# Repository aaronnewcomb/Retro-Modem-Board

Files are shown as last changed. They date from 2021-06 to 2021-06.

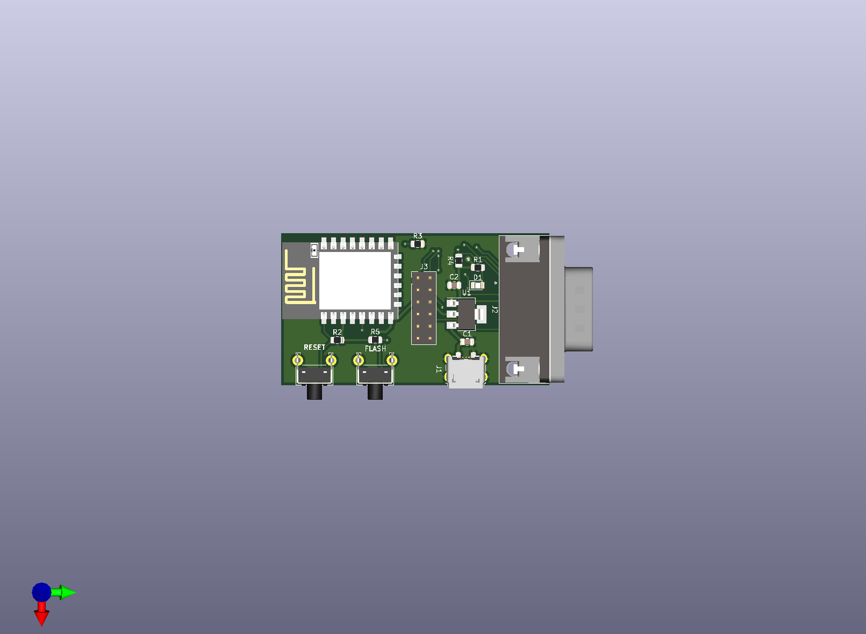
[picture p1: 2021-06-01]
KiCAD/RetroWIFI.png

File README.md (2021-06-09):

# Retro-Modem-Board
This is the PCB I built to be used with the Zmodem project

RetroWIFI

This boards uses an ESP8266 in the form of an ESP-12E/F module along with some simple parts to act as a modem/wifi bridge. It was initially built to be used with this Zmodem project. https://github.com/bozimmerman/Zimodem

3D printable case available here https://www.thingiverse.com/thing:4876405
## Video
thumbnail030 (https://youtu.be/1vX6TcwniQ4)

## BOM

\*All caps and resistors are 0805/2012
Label | Part
------------ | -------------
C1, C2 | 10uF Capacitor
C3 - C7 | .1uF Capacitor
D1 | 0805 LED
J1 | USB Micro-B socket
J2 | 9 Pin Female DSUB 4.94mm Edge Pin Offset
J3 | 02x06 Pin Header
R1 | 470 Ohm Resistor
R2 - R5 | 1K Ohm Resistor
SW1, SW2 | Push Button Right Angle
U1 | NCP1117ST33T3G
U2 | MAX3232
U3 | ESP-12E/F Module

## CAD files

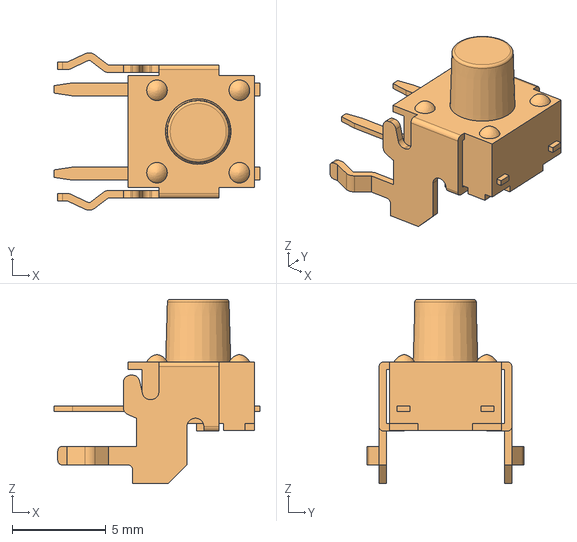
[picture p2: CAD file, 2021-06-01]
KiCAD/TL1105XFxxxx.stp
11.0 x 8.40 x 9.85 mm

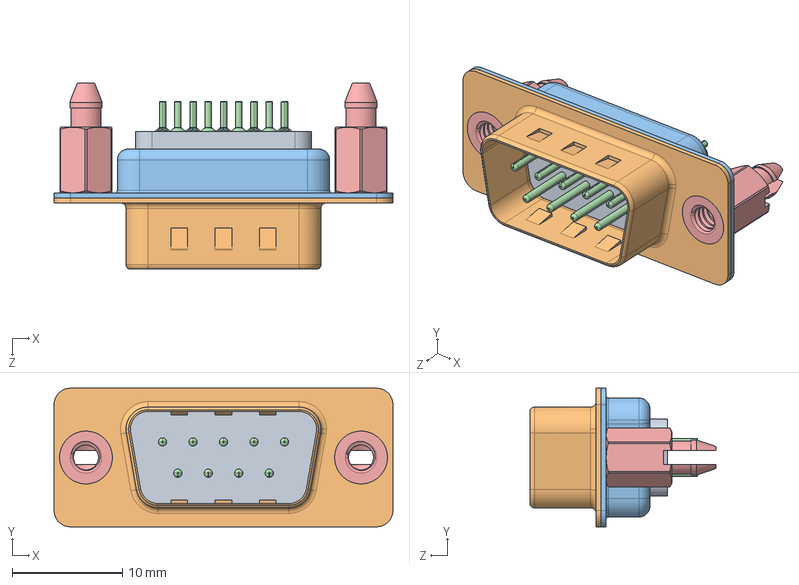
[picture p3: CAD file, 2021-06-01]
KiCAD/627-009-220-046 - EDAC D-Sub Connector.STEP
30.8 x 12.6 x 16.9 mm
627 Housing_09 LP
627 Shell Front_09 Contacts
627 Shell Rear_09 Contacts
627 Contact Row 1_20L x 5
627 Contact Row 2_20L x 4
627 4-40 Threaded Boardlock_LP x 2

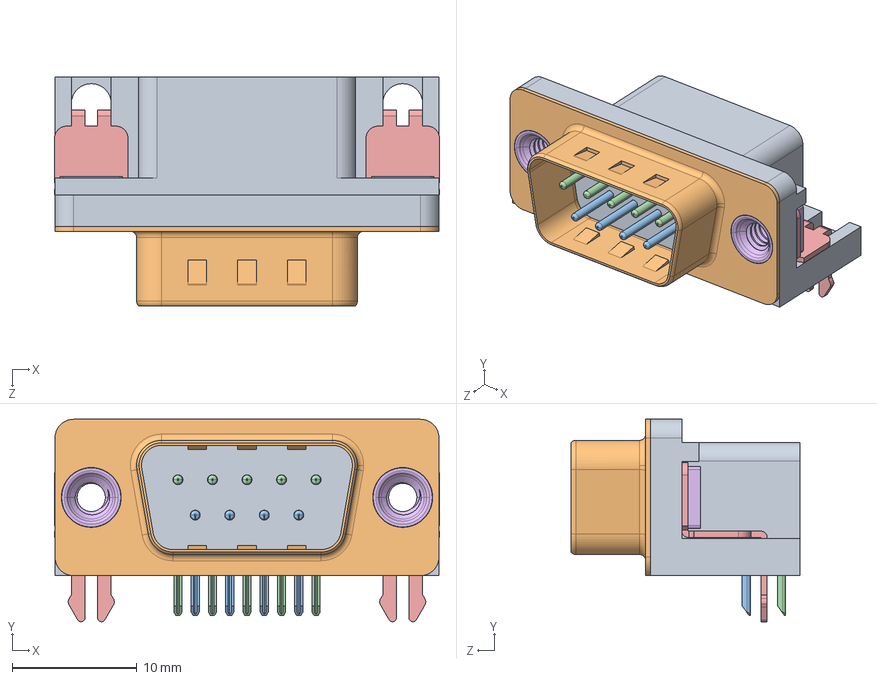
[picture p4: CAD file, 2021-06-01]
KiCAD/621-009-260-042 - EDAC D-Sub Connector.STEP
30.9 x 16.2 x 18.4 mm
621 Housing_9 Socket
621 Shell_9 Socket
621 Contact Bottom x 4
621 Contact Top x 5
621 2 Prong Board Lock x 2
621 4-40 Threaded Rivet x 2

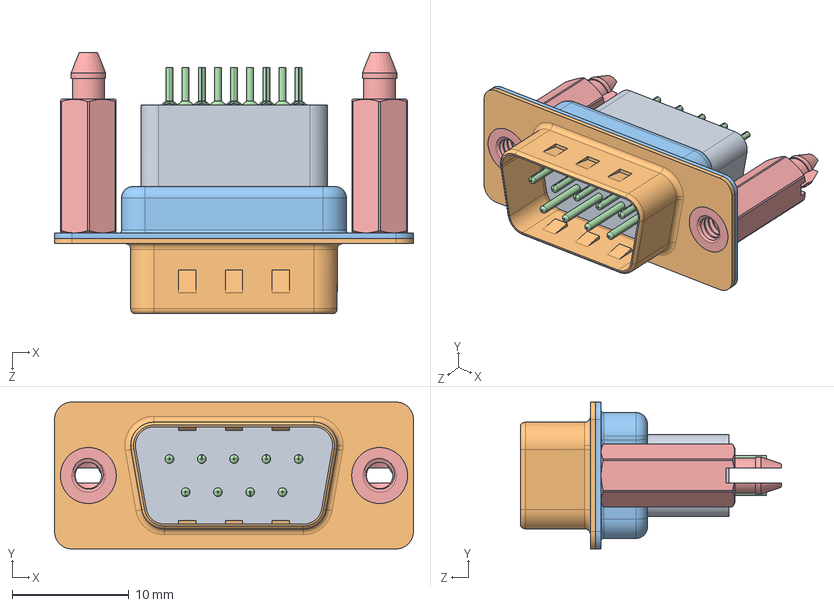
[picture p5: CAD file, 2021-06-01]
KiCAD/627-009-221-556 - EDAC D-Sub Connector.STEP
30.8 x 12.6 x 22.4 mm
627 Housing_09 HP
627 Shell Front_09 Contacts
627 Shell Rear_09 Contacts
627 Contact Row 1_21H x 5
627 Contact Row 2_21H x 4
627 4-40 Threaded Boardlock_HP x 2

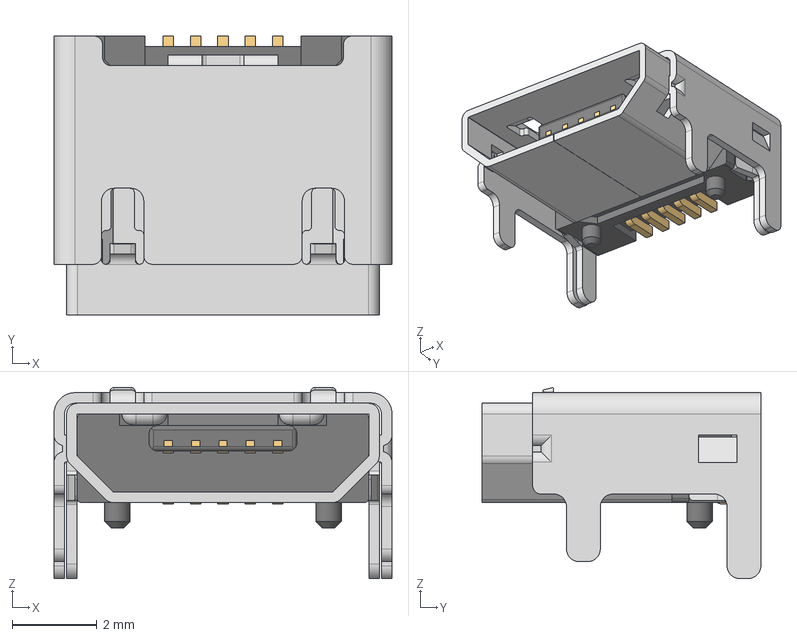
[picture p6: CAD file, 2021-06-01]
KiCAD/629105150521_Download_STP_629105150521_rev1.stp
8.00 x 6.60 x 4.52 mm
629105150521_Housing
629105150521_Pin1 x 4
629105150521_Pin2
629105150521_Shielding2
629105150521_Shielding

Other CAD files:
KiCAD/627-009-221-056 - EDAC D-Sub Connector.STEP

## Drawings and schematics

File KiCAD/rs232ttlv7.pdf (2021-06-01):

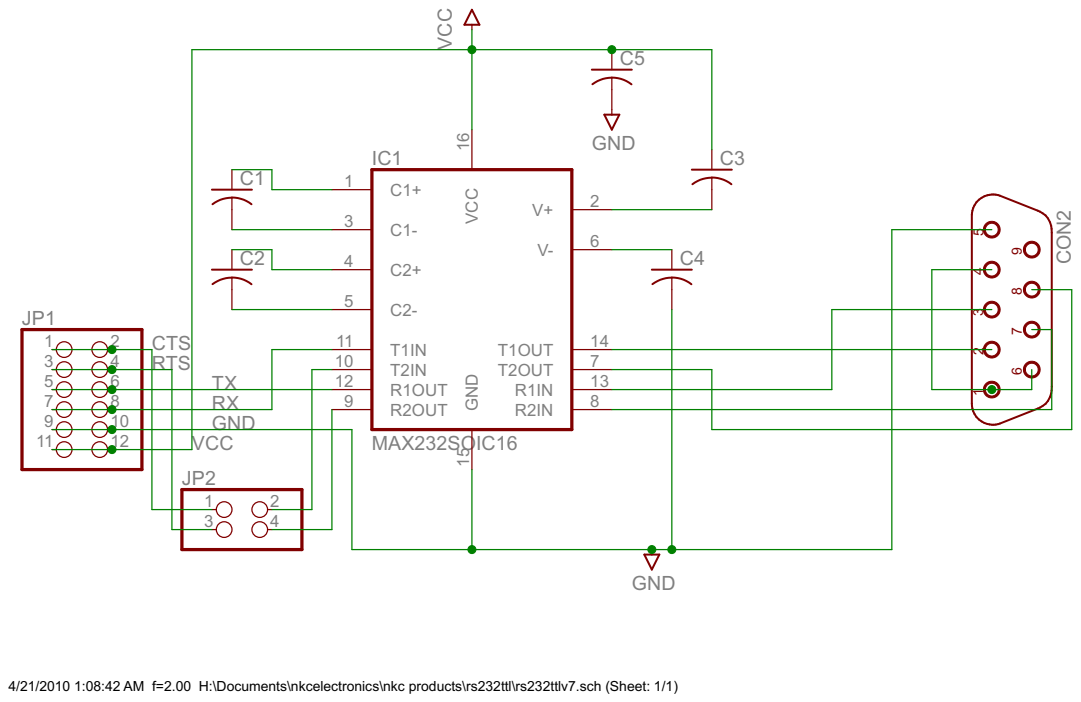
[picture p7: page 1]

4/21/2010 1:08:42 AM f=2.00 H:\Documents\nkcelectronics\nkc products\rs232ttl\rs232ttlv7.sch (Sheet: 1/1)

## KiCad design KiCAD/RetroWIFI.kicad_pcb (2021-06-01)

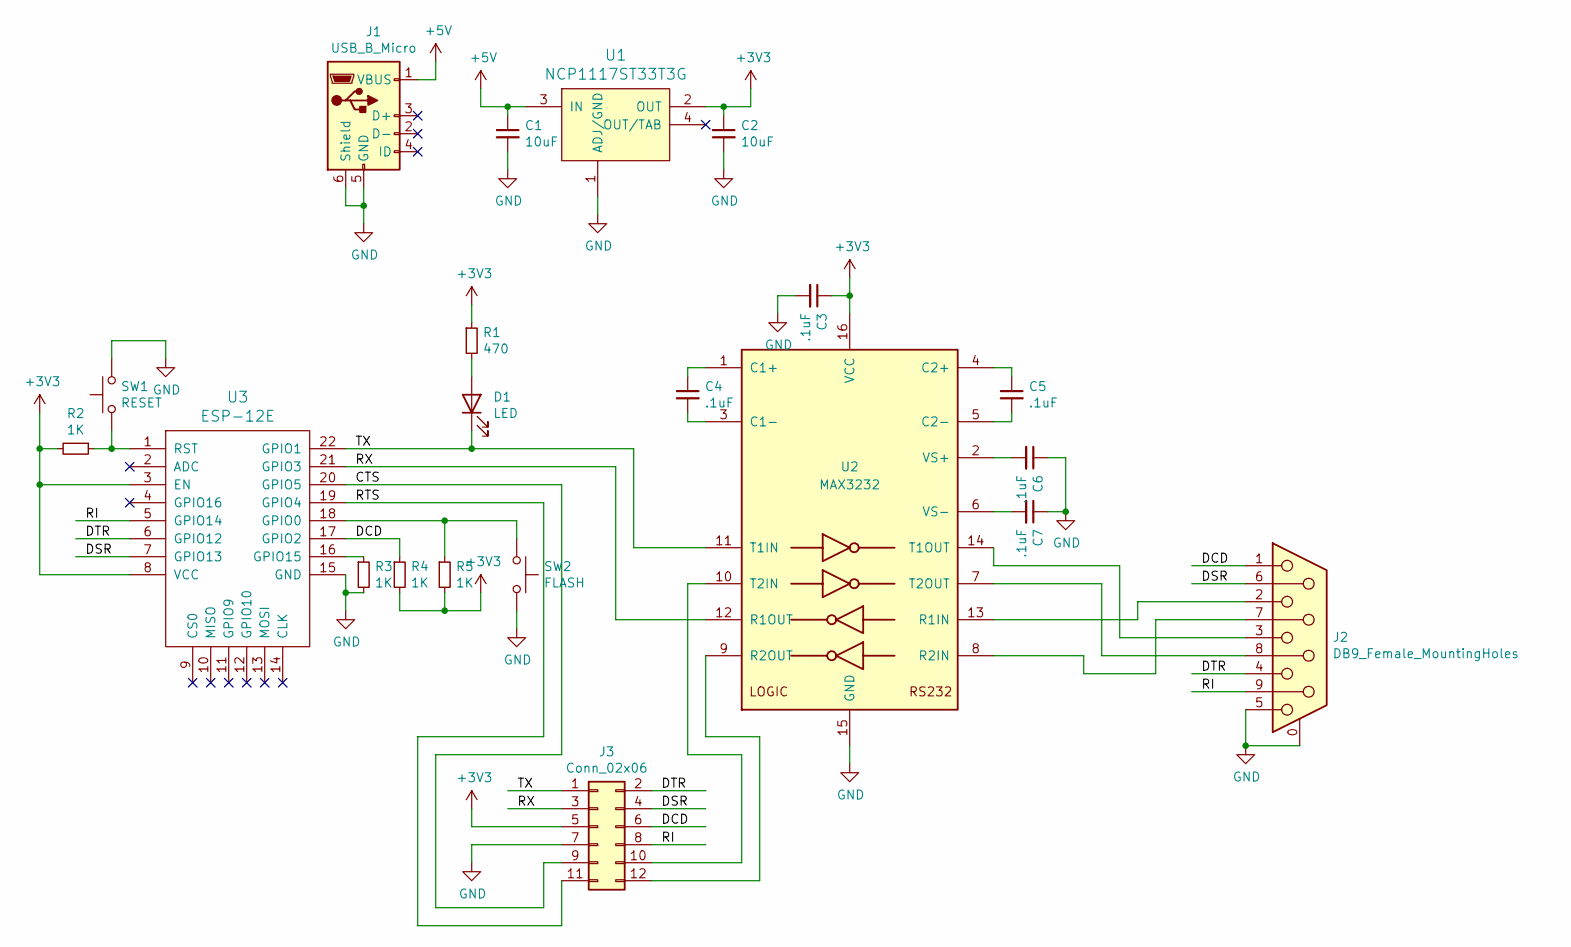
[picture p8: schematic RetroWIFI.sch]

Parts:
C1, C2: 10uF; C_0805_2012Metric
C3, C4, C5, C6, C7: .1uF; C_0805_2012Metric
D1: LED; LED_0805_2012Metric
J1: USB_B_Micro; USB_Micro-B_Wuerth_629105150521
J2: DB9_Female_MountingHoles; DSUB-9_Female_Horizontal_P2.77x2.84mm_EdgePinOffset4.94mm_H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
J3: Conn_02x06; PinHeader_2x06_P2.54mm_Vertical
R1: 470; R_0805_2012Metric
R2, R3, R4, R5: 1K; R_0805_2012Metric
SW1: RESET; SW_Tactile_SKHH_Angled
SW2: FLASH; SW_Tactile_SKHH_Angled
U1: NCP1117ST33T3G; SOT-223; MPN NCP1117ST33T3G; Digi-Key_PN NCP1117ST33T3GOSCT-ND
U2: MAX3232; SOIC-16_3.9x9.9mm_P1.27mm
U3: ESP-12E

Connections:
+3V3: C2.1, C3.1, J3.5, R1.1, R2.2, R4.2, R5.2, U1.2 (OUT), U2.16 (VCC), U3.3 (EN), U3.8 (VCC)
+5V: C1.1, J1.1 (VBUS), U1.3 (IN)
/CTS: J3.9, U3.20 (GPIO5)
/DCD: J2.1, J3.6, R4.1, U3.17 (GPIO2)
/DSR: J2.6, J3.4, U3.7 (GPIO13)
/DTR: J2.4, J3.2, U3.6 (GPIO12)
/RI: J2.9, J3.8, U3.5 (GPIO14)
/RTS: J3.11, U3.19 (GPIO4)
/RX: J3.3, U2.12 (R1OUT), U3.21 (GPIO3)
/TX: D1.1 (K), J3.1, U2.11 (T1IN), U3.22 (GPIO1)
GND: C1.2, C2.2, C3.2, C6.1, C7.1, J1.5 (GND), J1.6 (Shield), J2.0 (PAD), J2.5, J3.7, R3.2, SW1.2, SW2.2, U1.1 (ADJ/GND), U2.15 (GND), U3.15 (GND)
unnamed: C4.1, U2.1 (C1+)
unnamed: C4.2, U2.3 (C1-)
unnamed: C5.1, U2.4 (C2+)
unnamed: C5.2, U2.5 (C2-)
unnamed: C6.2, U2.2 (VS+)
unnamed: C7.2, U2.6 (VS-)
unnamed: D1.2 (A), R1.2
unnamed: J2.2, U2.13 (R1IN)
unnamed: J2.3, U2.14 (T1OUT)
unnamed: J2.7, U2.8 (R2IN)
unnamed: J2.8, U2.7 (T2OUT)
unnamed: J3.10, U2.10 (T2IN)
unnamed: J3.12, U2.9 (R2OUT)
unnamed: R2.1, SW1.1, U3.1 (RST)
unnamed: R3.1, U3.16 (GPIO15)
unnamed: R5.1, SW2.1, U3.18 (GPIO0)

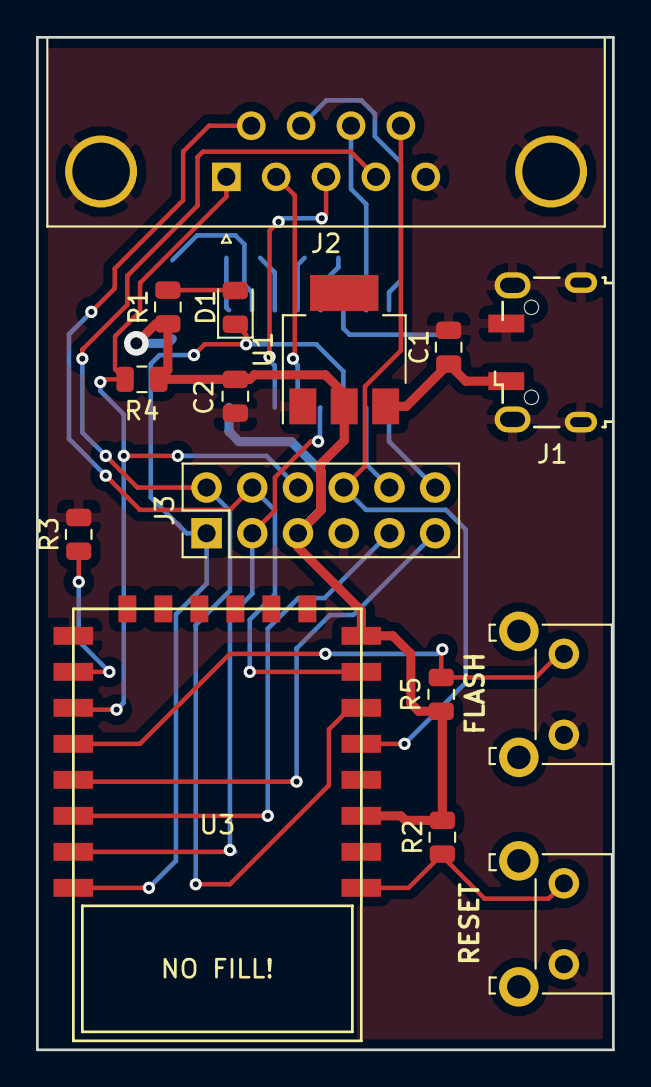
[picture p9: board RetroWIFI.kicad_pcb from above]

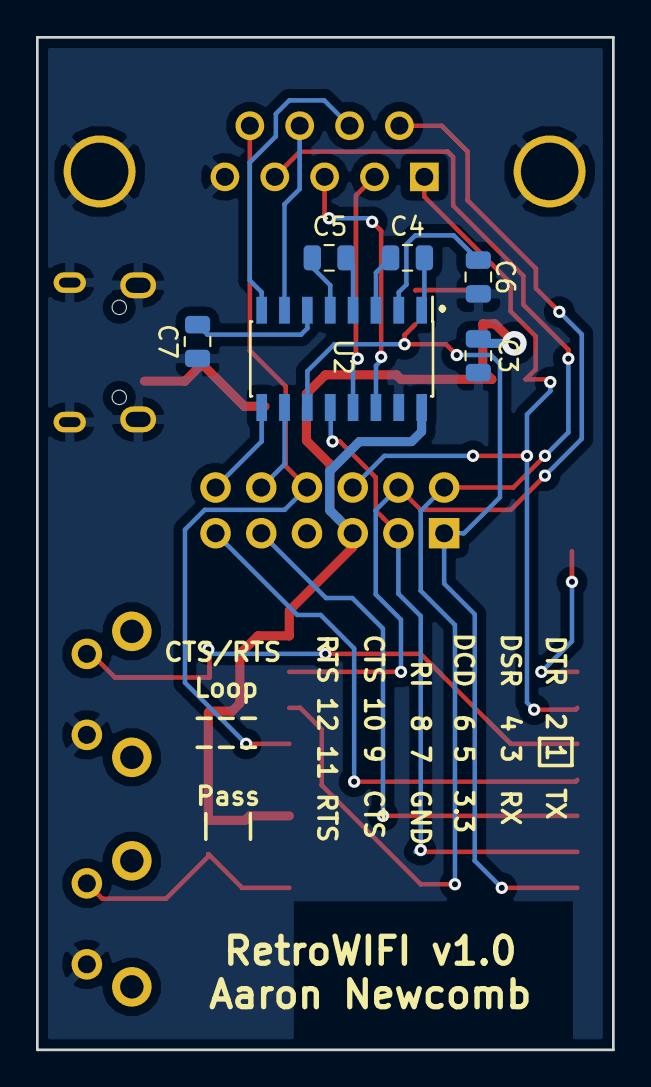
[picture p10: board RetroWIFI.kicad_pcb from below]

Board: 2 copper layers, 32.0 x 56.2 mm, 21 parts (6 on the bottom side), 27 nets.

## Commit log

2021-06-01 Initail file upload
    [621-009-260-042 - EDAC D-Sub Connector.STEP, 627-009-220-046 - EDAC D-Sub Connector.STEP, 627-009-221-056 - EDAC D-Sub Connector.STEP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]
2021-06-01 Initial file upload
    [621-009-260-042 - EDAC D-Sub Connector.STEP, 627-009-220-046 - EDAC D-Sub Connector.STEP, 627-009-221-056 - EDAC D-Sub Connector.STEP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]
2021-06-01 Added BOM
